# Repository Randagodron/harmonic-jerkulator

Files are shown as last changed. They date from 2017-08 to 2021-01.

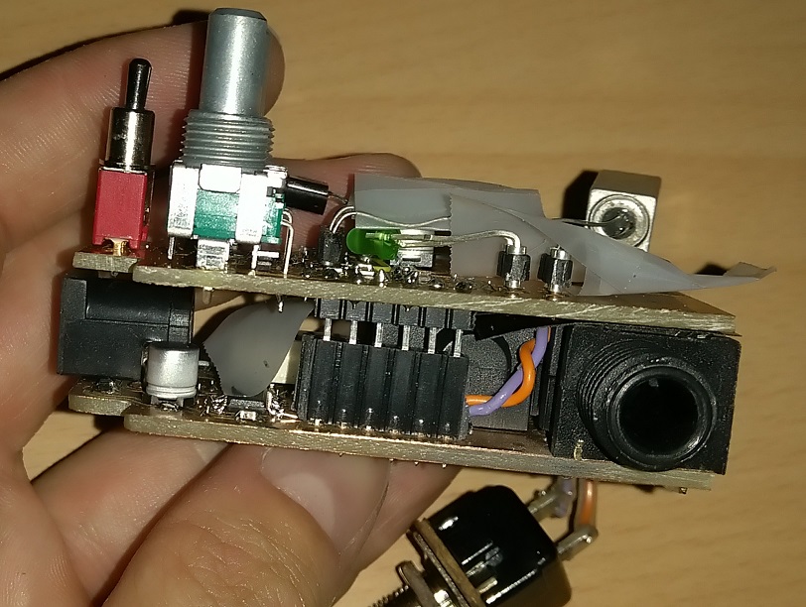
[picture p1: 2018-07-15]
export/harmonic_jerkulator_finished_05.jpg

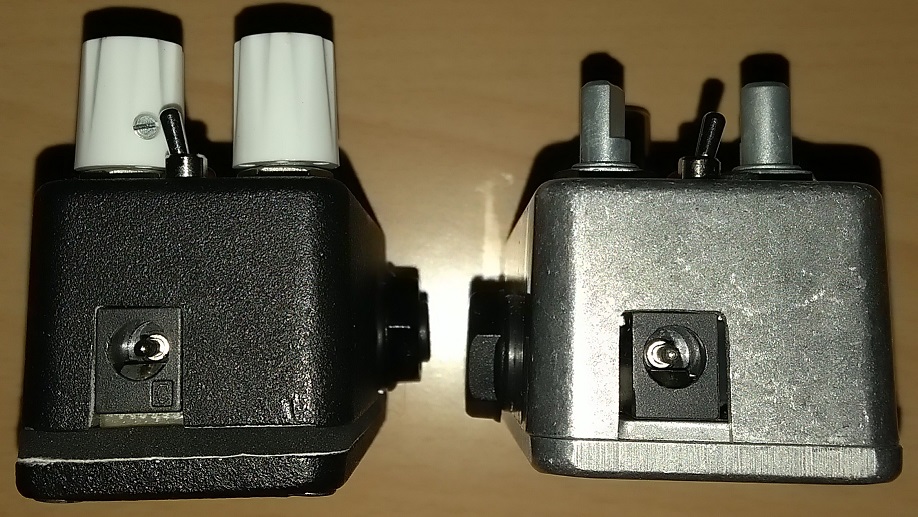
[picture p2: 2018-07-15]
export/harmonic_jerkulator_finished_02.jpg

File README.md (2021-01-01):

# harmonic-jerkulator
Fuzz stompbox for electric guitar

This circuit is based on the Harmonic Jerkulator from Tim Escobedo, itself based on the Interfax Harmonic Percolator.

CAD done with KiCAD, simulation done with LTSpice.

Companion article (in french) : http://blog.randagodron.eu/index.php?post/2017/12/23/DIY-audio-Harmonic-Jerkulator

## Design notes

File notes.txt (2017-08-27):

A acheter:

- connecteur inter-cartes long (au moins 15mm)
- jacks fins, CLIFF S1 / FCR11155 / FCR50051 ou pro signal MX
- capa 22u electrolythique, plat (moins que 7.45mm)
- switch SPDT 3 pos. pins longues (au moins 10mm)

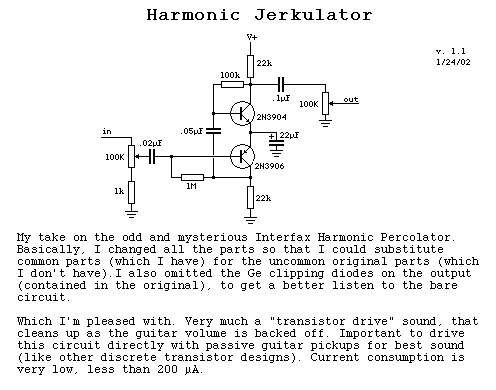
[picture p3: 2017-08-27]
doc/harmonicjerkulator.gif

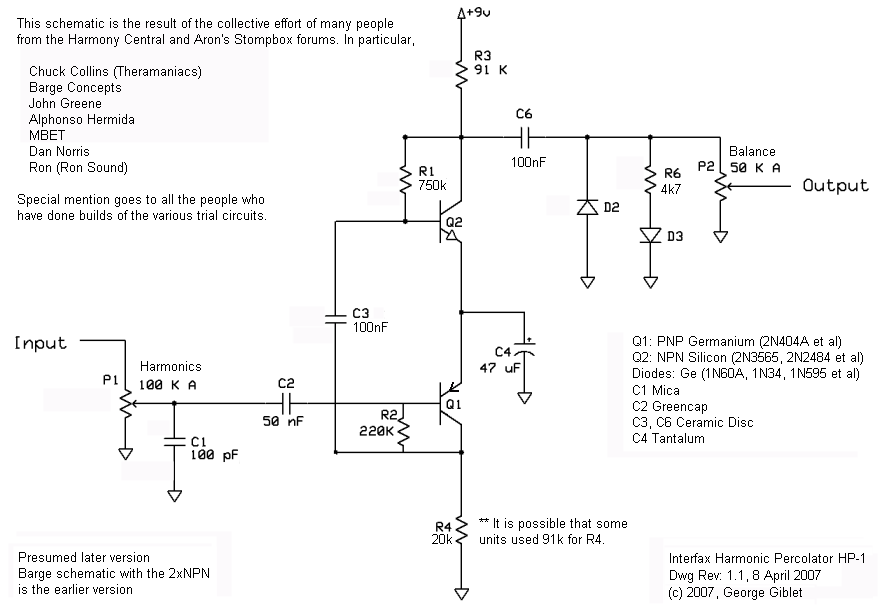
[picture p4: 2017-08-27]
doc/HarmonicPercolator.sch.png

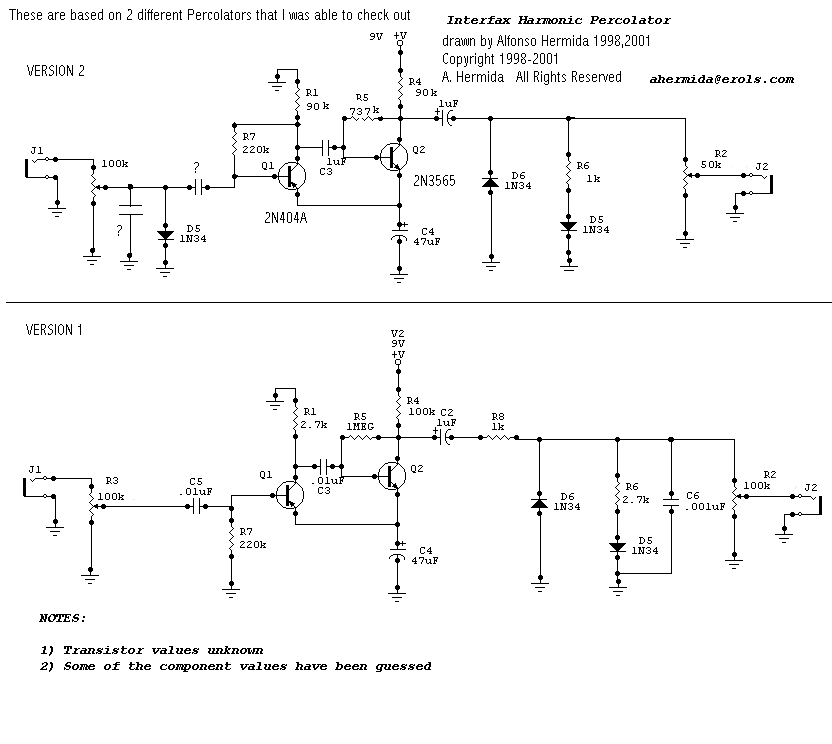
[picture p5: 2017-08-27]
doc/harmonic_percolator.gif

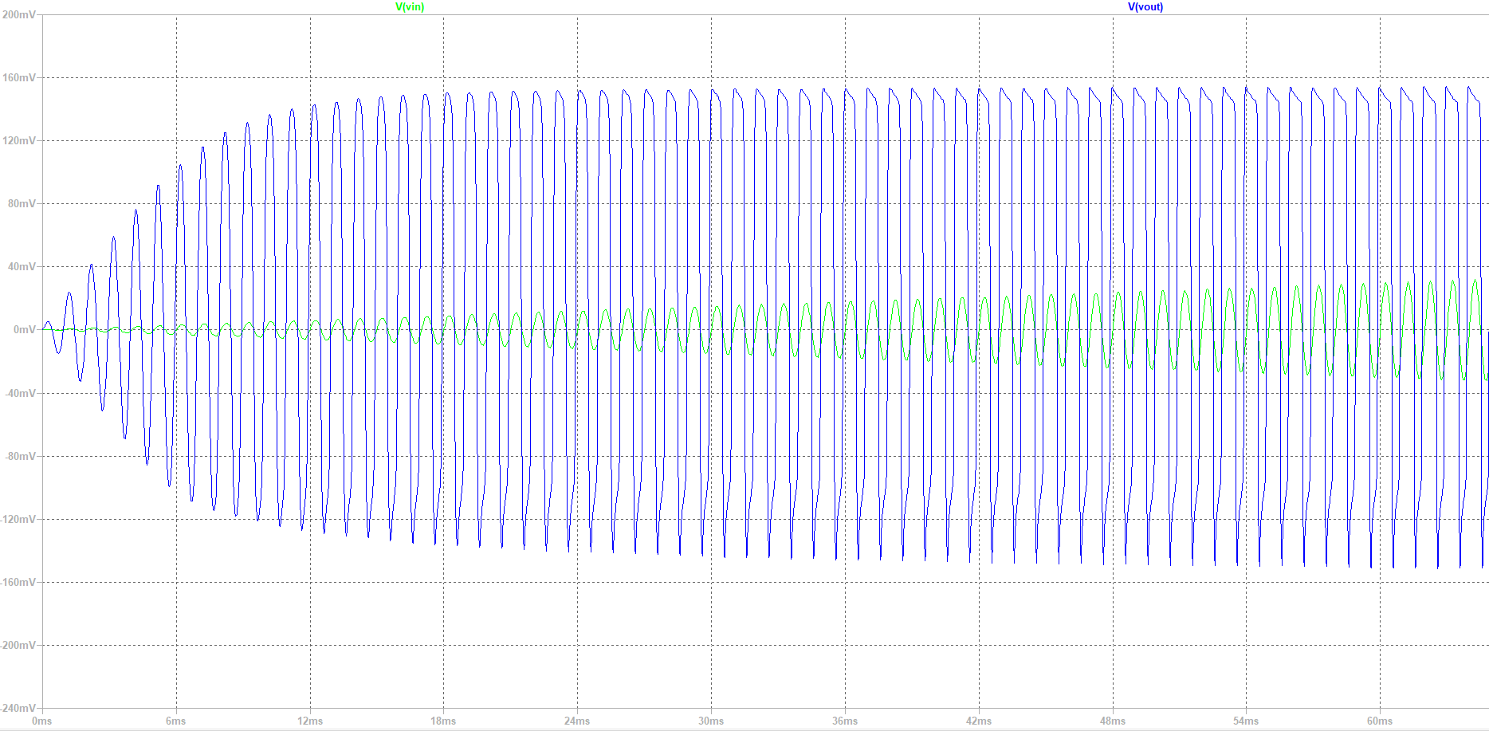
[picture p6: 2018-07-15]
export/spice_graph_01.PNG

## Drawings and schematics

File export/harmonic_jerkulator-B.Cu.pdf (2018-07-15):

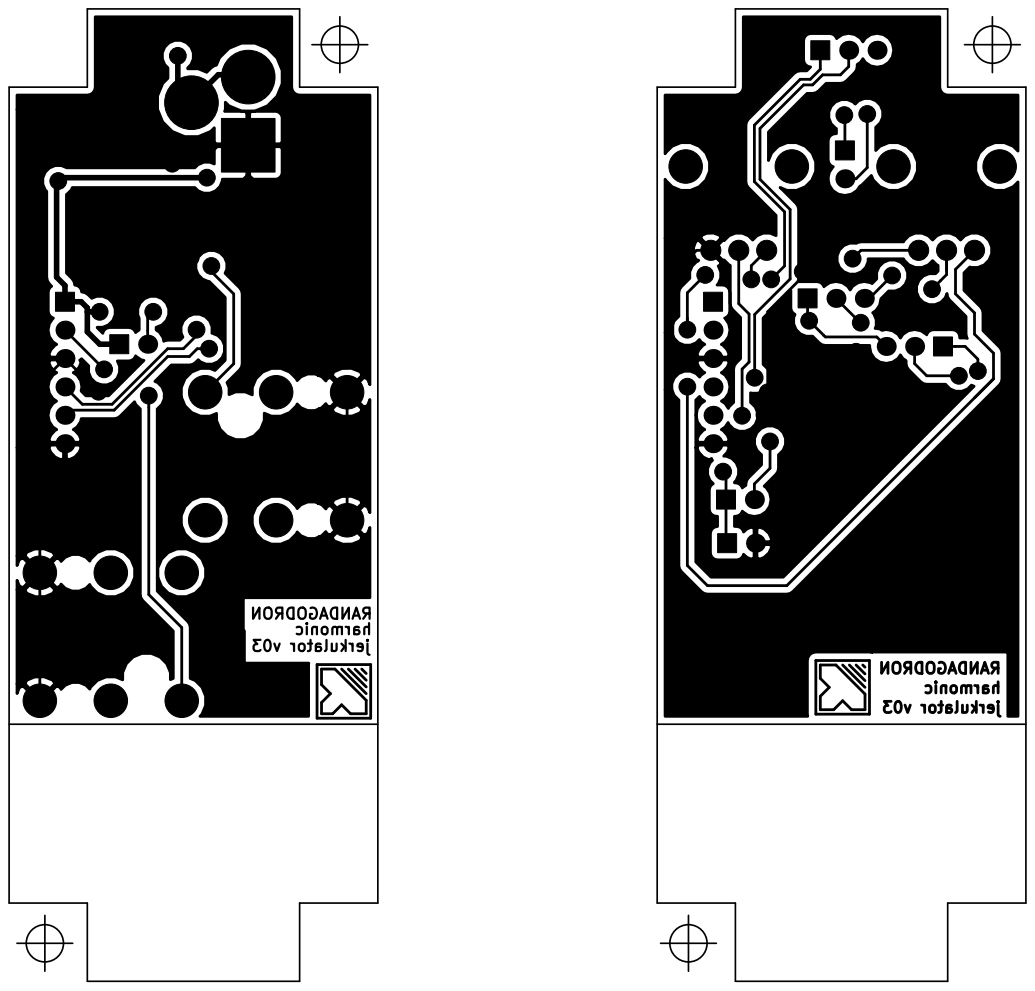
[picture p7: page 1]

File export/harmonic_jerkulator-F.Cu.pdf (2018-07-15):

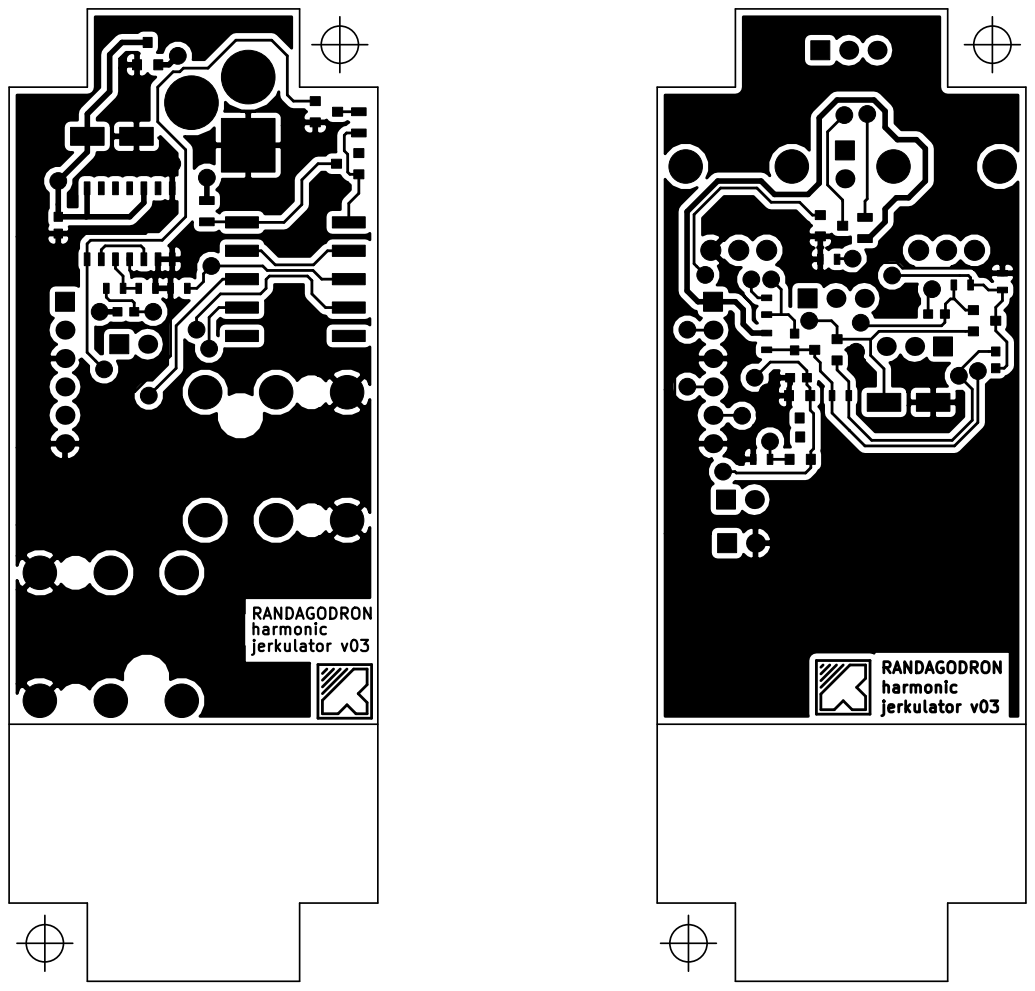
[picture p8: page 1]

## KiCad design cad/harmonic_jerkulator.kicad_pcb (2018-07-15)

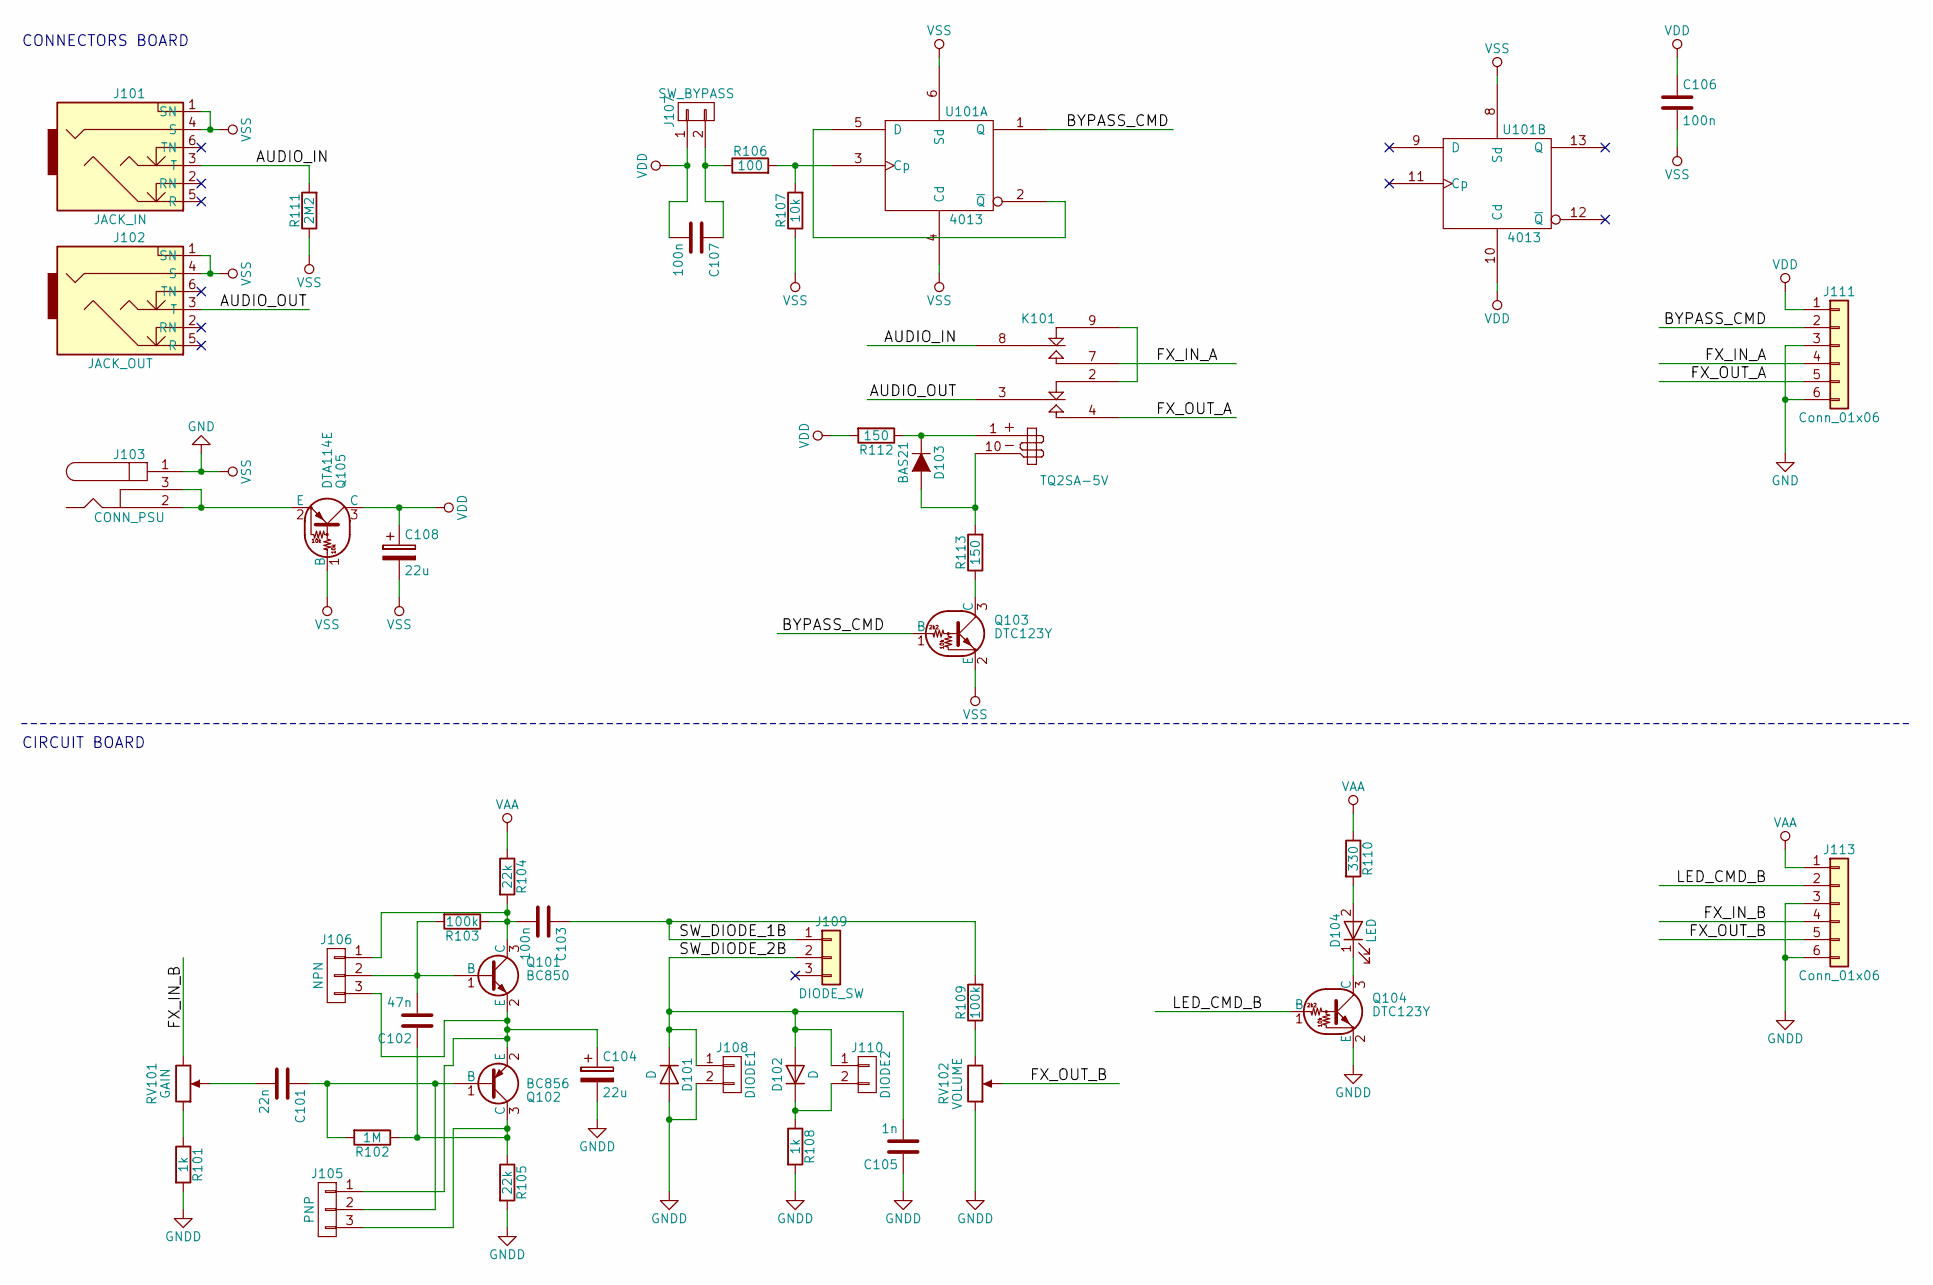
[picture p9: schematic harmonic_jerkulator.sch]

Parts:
C101: 22n; C_0603
C102: 47n; C_0603
C103, C106, C107: 100n; C_0603
C104, C108: 22u; CP_Elec_5x5.3
C105: 1n; C_0603
D101, D102: D; SOT-23
D103: BAS21; SOT-23
D104: LED; Pin_Header_Straight_1x02_Pitch2.54mm
J101: JACK_IN; CLIFF_FCR5005x
J102: JACK_OUT; CLIFF_FCR5005x
J103: CONN_PSU; JACK_ALIM
J105: PNP; Pin_Header_Straight_1x03_Pitch2.54mm
J106: NPN; Pin_Header_Straight_1x03_Pitch2.54mm
J107: SW_BYPASS; Pin_Header_Straight_1x02_Pitch2.54mm
J108: DIODE1; Pin_Header_Straight_1x02_Pitch2.54mm
J109: DIODE_SW; Pin_Header_Straight_1x03_Pitch2.54mm
J110: DIODE2; Pin_Header_Straight_1x02_Pitch2.54mm
J111, J113: Conn_01x06; Pin_Header_Straight_1x06_Pitch2.54mm
K101: TQ2SA-5V; TQ2SA
Q101: BC850; SOT-23
Q102: BC856; SOT-23
Q103, Q104: DTC123Y; SOT-23
Q105: DTA114E; SOT-23
R101, R108: 1k; R_0603
R102: 1M; R_0603
R103, R109: 100k; R_0603
R104, R105: 22k; R_0603
R106: 100; R_0603
R107: 10k; R_0603
R110: 330; R_0805
R111: 2M2; R_0603
R112, R113: 150; R_0805
RV101: GAIN; ALPS_RK09L
RV102: VOLUME; ALPS_RK09L
U101: 4013; SOIC-14_N

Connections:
/AUDIO_IN: J101.3 (T), K101.8 (C2), R111.2
/AUDIO_OUT: J102.3 (T), K101.3 (C1)
/BYPASS_CMD: J111.2, Q103.1 (B), U101.1 (Q)
/FX_IN_A: J111.4, K101.7 (T2)
/FX_IN_B: J113.4, RV101.3
/FX_OUT_A: J111.5, K101.4 (T1)
/FX_OUT_B: J113.5, RV102.2
/LED_CMD_B: J113.2, Q104.1 (B)
/SW_DIODE_1B: C103.1, J109.1, R109.2
/SW_DIODE_2B: C105.2, D101.1 (K), D102.2 (A), J108.1, J109.2, J110.1
GND: C106.2, C108.2, J101.1 (SN), J101.4 (S), J102.1 (SN), J102.4 (S), J103.1, J111.3, J111.6, Q103.2 (E), Q105.1 (B), R107.1, R111.1, U101.4 (Cd), U101.6 (Sd), U101.7 (VSS), U101.8 (Sd)
GNDD: C104.2, C105.1, D101.2 (A), J108.2, J113.3, J113.6, Q104.2 (E), R101.2, R105.2, R108.2, RV102.1
unnamed: C101.1, J105.2, Q102.1 (B), R102.2
unnamed: C101.2, RV101.2
unnamed: C102.1, J105.3, Q102.3 (C), R102.1, R105.1
unnamed: C102.2, J106.2, Q101.1 (B), R103.2
unnamed: C103.2, J106.1, Q101.3 (C), R103.1, R104.2
unnamed: C104.1, J105.1, J106.3, Q101.2 (E), Q102.2 (E)
unnamed: C107.1, J107.2, R106.1
unnamed: D102.1 (K), J110.2, R108.1
unnamed: D103.1 (A), K101.10 (-), R113.2
unnamed: D103.3 (K), K101.1 (+), R112.1
unnamed: D104.1 (K), Q104.3 (C)
unnamed: D104.2 (A), R110.2
unnamed: J103.2, J103.3, Q105.2 (E)
unnamed: K101.2 (R1), K101.9 (R2)
unnamed: Q103.3 (C), R113.1
unnamed: R101.1, RV101.1
unnamed: R106.2, R107.2, U101.3 (Cp)
unnamed: R109.1, RV102.3
unnamed: U101.2 (~Q), U101.5 (D)
VAA: J113.1, R104.1, R110.1
VDD: C106.1, C107.2, C108.1, J107.1, J111.1, Q105.3 (C), R112.2, U101.10 (Cd), U101.14 (VDD)

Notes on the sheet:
CONNECTORS BOARD
CIRCUIT BOARD

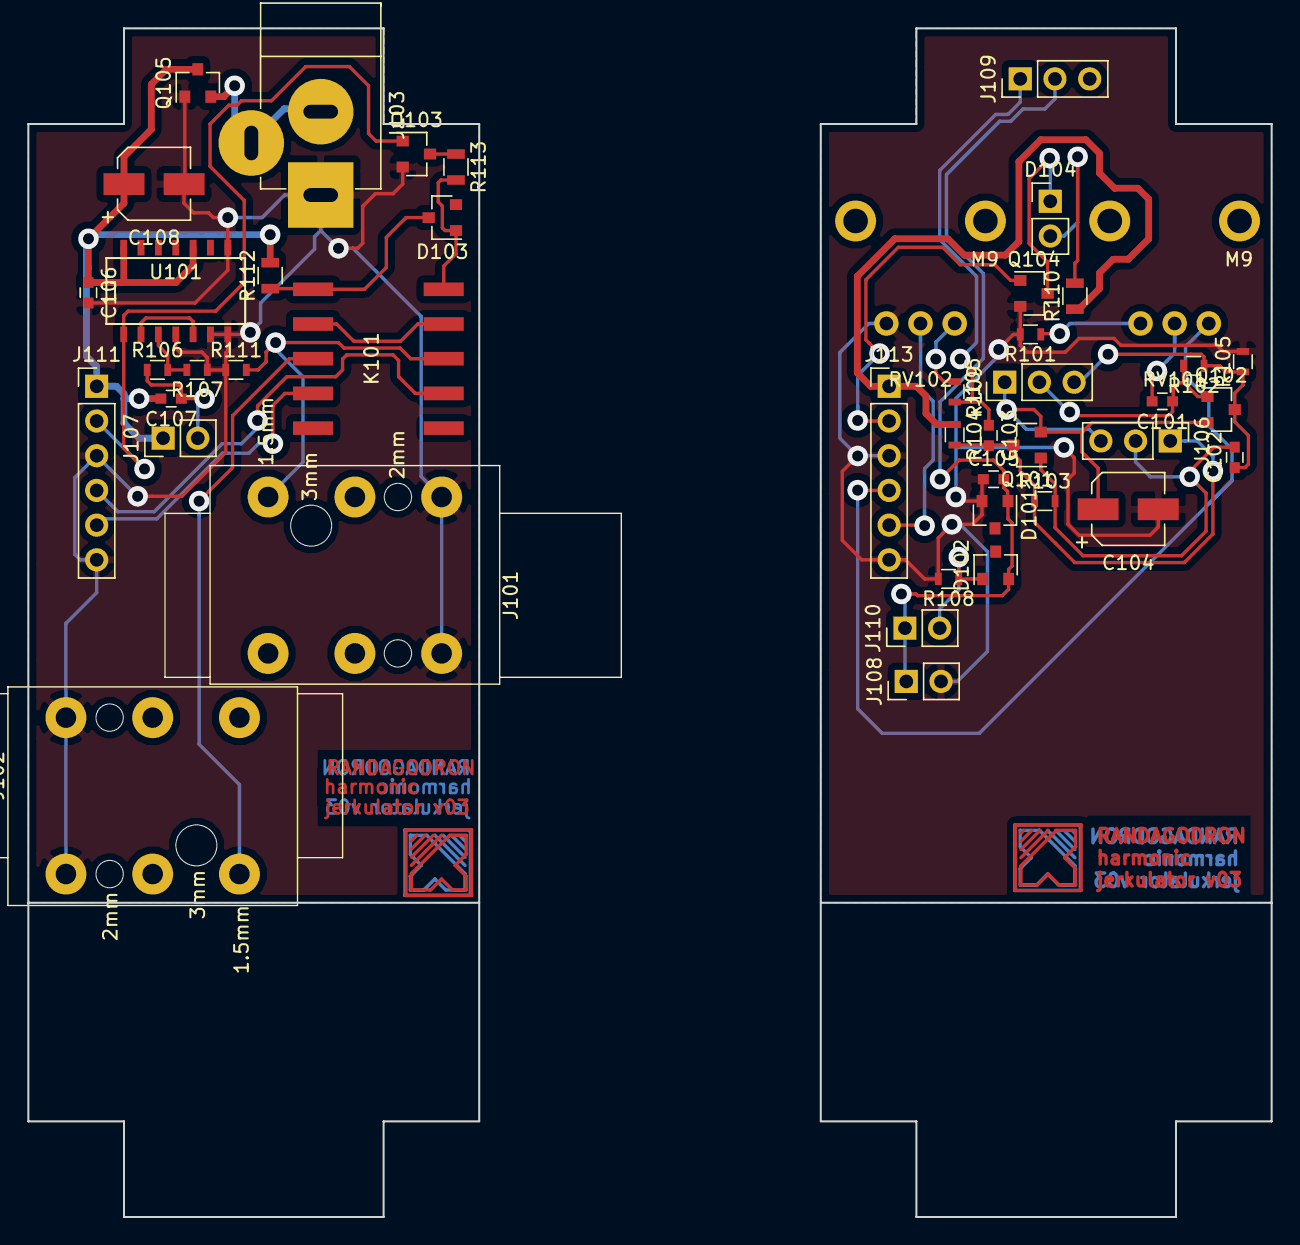
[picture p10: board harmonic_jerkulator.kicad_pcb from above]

Board: 2 copper layers, 91.0 x 87.0 mm, 45 parts (0 on the bottom side), 33 nets.

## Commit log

2017-08-27 Checked mechanics.
    Components placed.
    [harmonic_jerkulator.kicad_pcb]
2017-08-29 Corrected schematic : serial resistors on relay coil. Started layout.
    [harmonic_jerkulator.kicad_pcb, harmonic_jerkulator.sch]
2017-08-29 Corrected pots polarity.
    Connected GND and VSS.
    Done single-side layout on Connectors board.
    [harmonic_jerkulator.kicad_pcb, harmonic_jerkulator.sch]
2017-08-31 Finished layout.
    [harmonic_jerkulator.kicad_pcb]
2017-12-09 Corrections on layout.
    Exported layout.
    [harmonic_jerkulator.kicad_pcb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]
2017-12-28 Corrections on schematic. Not finished.
    [harmonic_jerkulator.sch]
2017-12-28 Done corrections, issues #1 to #6.
    [harmonic_jerkulator.kicad_pcb, harmonic_jerkulator.sch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]
2017-12-28 Changed PSU connector. Corrected layout.
    [harmonic_jerkulator.kicad_pcb, harmonic_jerkulator.sch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]
2018-02-04 Added recorded samples of the pedal.
2018-03-18 Corrected unconnected net.
    [harmonic_jerkulator.kicad_pcb]
2018-04-19 Corrected jacks spacing.
    [harmonic_jerkulator.kicad_pcb]
2018-04-19 Exported Gerbers.
    [harmonic_jerkulator-B.Cu.gbr, harmonic_jerkulator-F.Cu.gbr]
2018-06-05 Corrected PCB revision number.
    [harmonic_jerkulator.kicad_pcb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]
2018-07-15 New samples.
    Images of the schematic (LTspice).
2018-07-15 Generated new samples.
    Added schematic and graph images.
    [harmonic_jerkulator.kicad_pcb]
